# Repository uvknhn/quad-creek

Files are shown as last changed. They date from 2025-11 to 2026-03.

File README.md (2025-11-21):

# Quad Creek
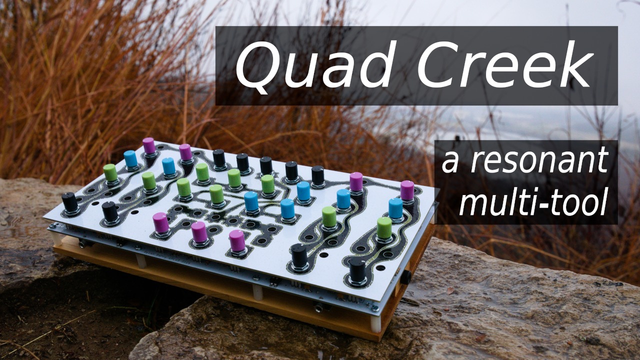
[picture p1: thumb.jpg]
Watch the video (https://www.youtube.com/watch?v=D_fRNRYVuKw)


[Webpage](https://loess-labs.net/inst/creek/)

[Etsy Shop](https://loesslabs.etsy.com)

[ASSEMBLY GUIDE](https://github.com/uvknhn/quad-creek/blob/main/docs/README.md)

Here's the page for my instrument, Quad Creek. The gerbers, source files, code, and schematics are available under the GNU GPLv3. Additionally you'll find a BOM in the build guide, which should be useful if you're building one. If you have any questions, email me at uvknhn@tutanota.com.

You can find the manual and other documentation on my webpage.

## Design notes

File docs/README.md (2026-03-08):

# How to assemble your Quad Creek kit/PCB

PCB_Step_0

Welcome! Here I'll walk you through the basic steps of how to solder a Quad Creek. This is NOT a beginner project, you don't have to be a seasoned veteran, but if this is your first time soldering, stop. Here I'll go over my general way of soldering, you don't have to do it exactly how I do, but this way is most efficient and easy for me. Solder with care. If you just got the PCB and not the DIY kit, refer to the BOM at the bottom of this page.

## Resistors & Diodes
PCB_Step_1
Solder these from the top. Make sure the diode band is on the same side as the silkscreen image, and make sure you put the BAT46s on the diodes with the S curve, and the 1N914s on the diodes with the straight band. If you're unsure of capacitor color codes, look it up. Lastly, make sure everything sits flush, you'll thank yourself later.

## Capacitors
PCB_Step_2
Also solder these from the top. Make sure the numbers match.

106\10uF Capacitor

Note the 10uF (106) capacitor that is soldered on the underside.

## IC Sockets, Transistors, & More
PCB_Step_3
To solder the IC sockets, insert, and then fold two opposite corner pins to secure the socket in place, and solder from the bottom. Ensure the notches are aligned, so no ICs are unintentionally placed upside-down. I solder the transistors from the bottom. You can do them from the top, but it's harder that way. Do not solder the voltage regulator backwards; very bad, high-temperature things happen when you do. Don't forget to do the jumpers either, you can use scrap leads to wire them as pictured.

## Power, Aux Jacks, & Other Bottom Components
PCB_Step_4
To solder the stereo aux jacks, I solder one pin to begin, then gently push the body of the jack to be flush, while the initial solder joint is being heated. Repeat for a second pin to anchor it, then solder the rest normally. This process is also used for the 2.1mm power jack. For the nano board, I socket the male pins into the female sockets, insert them into the PCB, place the nano board on top, solder the male pins to it, and then solder the female sockets to the board. This ensures the board can easily be inserted and removed from the board. Also if you bought a DIY kit the nano will come pre programmed, so you don't need to do anything there, though feel free to reprogram it if you'd like.

## Potentiometers
PCB_Step_5
**A note before soldering the potentiometers:** Use pliers or snippers to remove the small notch on top of the potentiometer, directly in front of the shaft. Soldering the poteniometers is a similar process to the aux. What I do is insert the potentiometers, solder just one pin on each pot, then when they've all had one joint soldered, I flip the board over and solder all 96 potentiometer pins from the bottom side. Do not solder the anchoring legs on the side until you're sure they're aligned enough to fit on the panel. You also don't need to solder them at all if you plan on screwing every potentiometer nut into the front panel.

## Final Steps

PCB_Step_6
PCB_Step_7

Once all your soldering is complete, test your quad creek. Turn the 5 mixer channels all the way counterclockwise, turn the 4 knobs at the tops of the creeks up the same, set the ones directly below those to about halfway, and see if there is sound coming out of the three outputs. If that works, I'd screw in all the banana jacks, the nylon standoffs, and do further testing with some banana plugs. Then once you have tested/feel confident it works, install the panel and enjoy!
**A note on installing the banana jacks:** Be wary not to overtighten. When tightening, hold the jack in place by applying downward pressure to the top of the jack, rather than holding from the sides. This prevents the plastic part at the top from being cross threaded and/or stripped out.

Also, if you got a PCB with no panel, or you simply want a custom panel, I've added a PDF with all of the holes from the original panel, which you can use as a reference for drilling and such.

There is also a PDF for the back panel, for drilling holes aligning with the standoffs.

## BILL OF MATERIALS

### RESISTORS

| Value | Qt. |
| :-- | --: |
| 1M | 6 |
| 100k | 56 |
| 10k | 35 |
| 1k | 18 |
| 2.2M | 1 |
| 220k | 17 |
| 22k | 12 |
| 2.2k | 2 |
| 47k | 6 |
| 4.7k | 1 |

### CAPACITORS

| Value | Code | Type | Qt. |
| :-- | :--: | :--: | --: |
| 220uF | 227 | Electr. | 1 |
| 10uF | 106 | MLCC | 7 |
| 4.7uF | 475 | MLCC | 2 |
| 1uF | 105 | MLCC | 16 |
| 100nF | 104 | MLCC | 32 |
| 10nF | 103 | MLCC | 10 |
| 1nF | 102 | MLCC | 12 |
| 100pF | 101 | MLCC | 1 |

### ICs

| Chip | Qt. |
| :-- | --: |
| TL082 | 6 |
| LM358 | 7 |
| CD4013 | 2 |
| L7809CV | 1 |
| ATMEGA328P Nano Board | 1 |

### TRANSISTORS

| Transistor | Qt. |
| :-- | --: |
| 2N3904 | 10 |
| BC548 | 1 |

### DIODES

| Diode | Qt. |
| :-- | --: |
| 1N914 | 25 |
| BAT46 | 16 |
| 1N4001 | 1 |

### I/O

| Part | Code | Qt. |
| :-- | :--: | --: |
| 4MM Banana | [Generic/Unknown](https://www.aliexpress.us/item/3256807503214936.html) | 32 |
| Potentiometer | RD901F-40-15K-B100K | 32 |
| Stereo Jack | PJ-324 | 5 |
| 2.1mm Jack | A-4118 | 1 |
| DIP Switch | DI-R02 | 2 |

### SOCKETS

| Type | Qt. |
| :-- | --: |
| 15 Pin Socket | 2 |
| 14 Pin DIP Socket | 2 |
| 8 Pin DIP Socket | 13 |

### Knobs
| Part | Code | Qt. |
| :-- | :--: | --: |
| Black Knob | [A-6351](https://www.taydaelectronics.com/black-control-knob-9-8x11mm-shaft-hole-6x18t.html)/["Stubby"](https://www.thonk.co.uk/shop/stubby-knobs-t18/) | 9 |
| Blue Knob | [A-6352](https://www.taydaelectronics.com/blue-control-knob-9-8x11mm-shaft-hole-6x18t.html) | 7 |
| Green Knob | [A-6353](https://www.taydaelectronics.com/green-control-knob-9-8-x-11mm-shaft-hole-6x18t.html) | 9 |
| Purple Knob | [A-5666](https://www.taydaelectronics.com/purple-control-knob-9-8-x-11mm-shaft-hole-6x18t-5666.html) | 7 |

### Mechanical
| Type | Qt. |
| :-- | --: |
| M3×15mm Nylon Standoff | 19 |
| M3×4mm Screw | 19 |
| M3×10mm Screw | 19 |

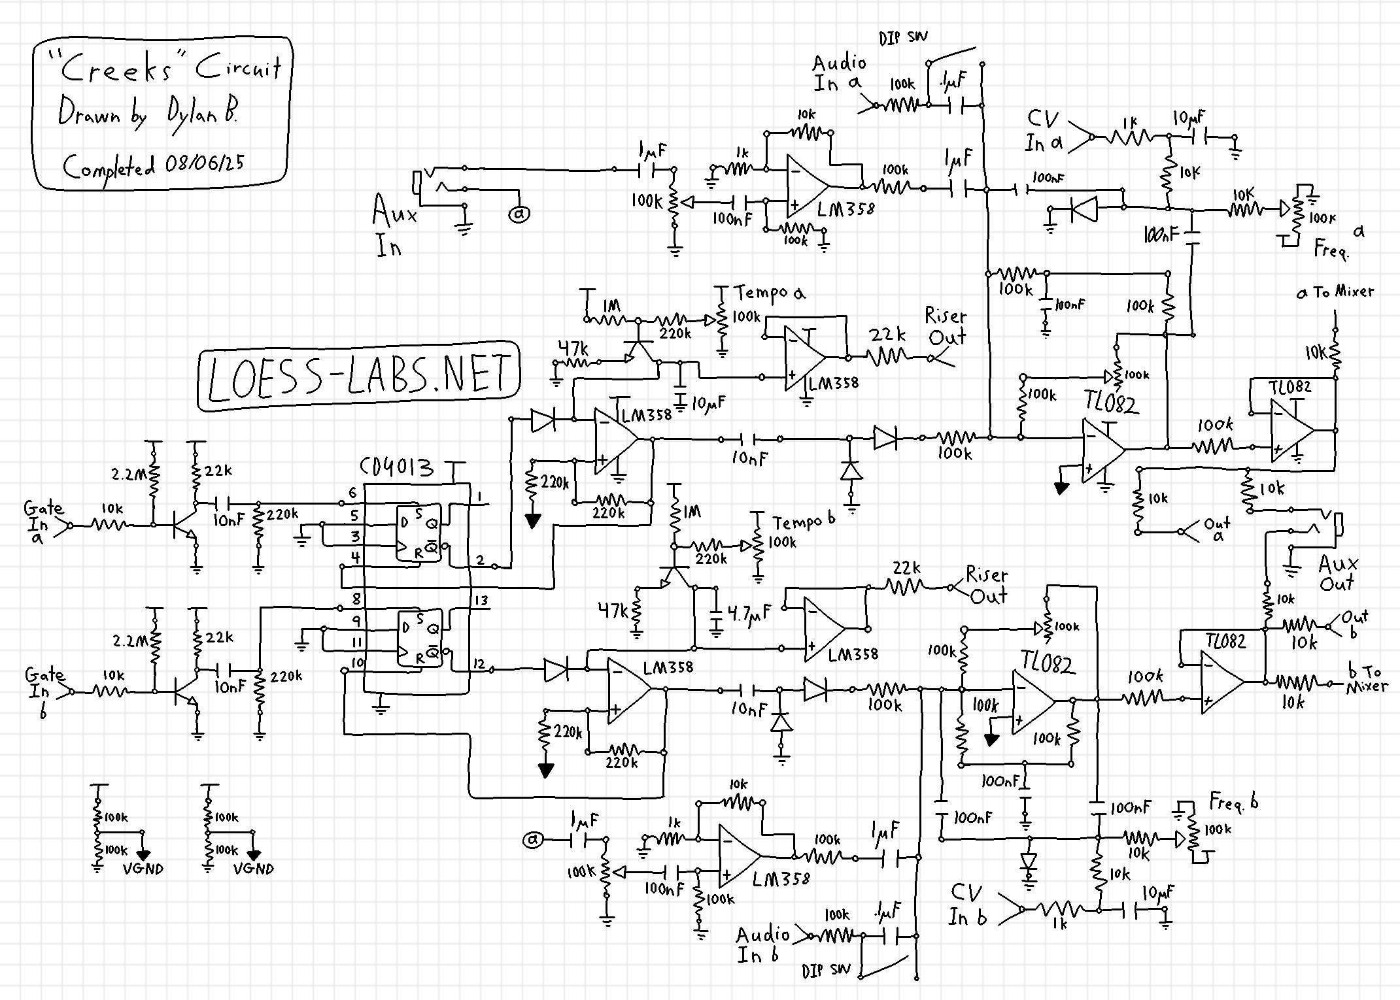
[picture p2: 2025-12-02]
docs/schem/The_Creeks_Schematic.gif

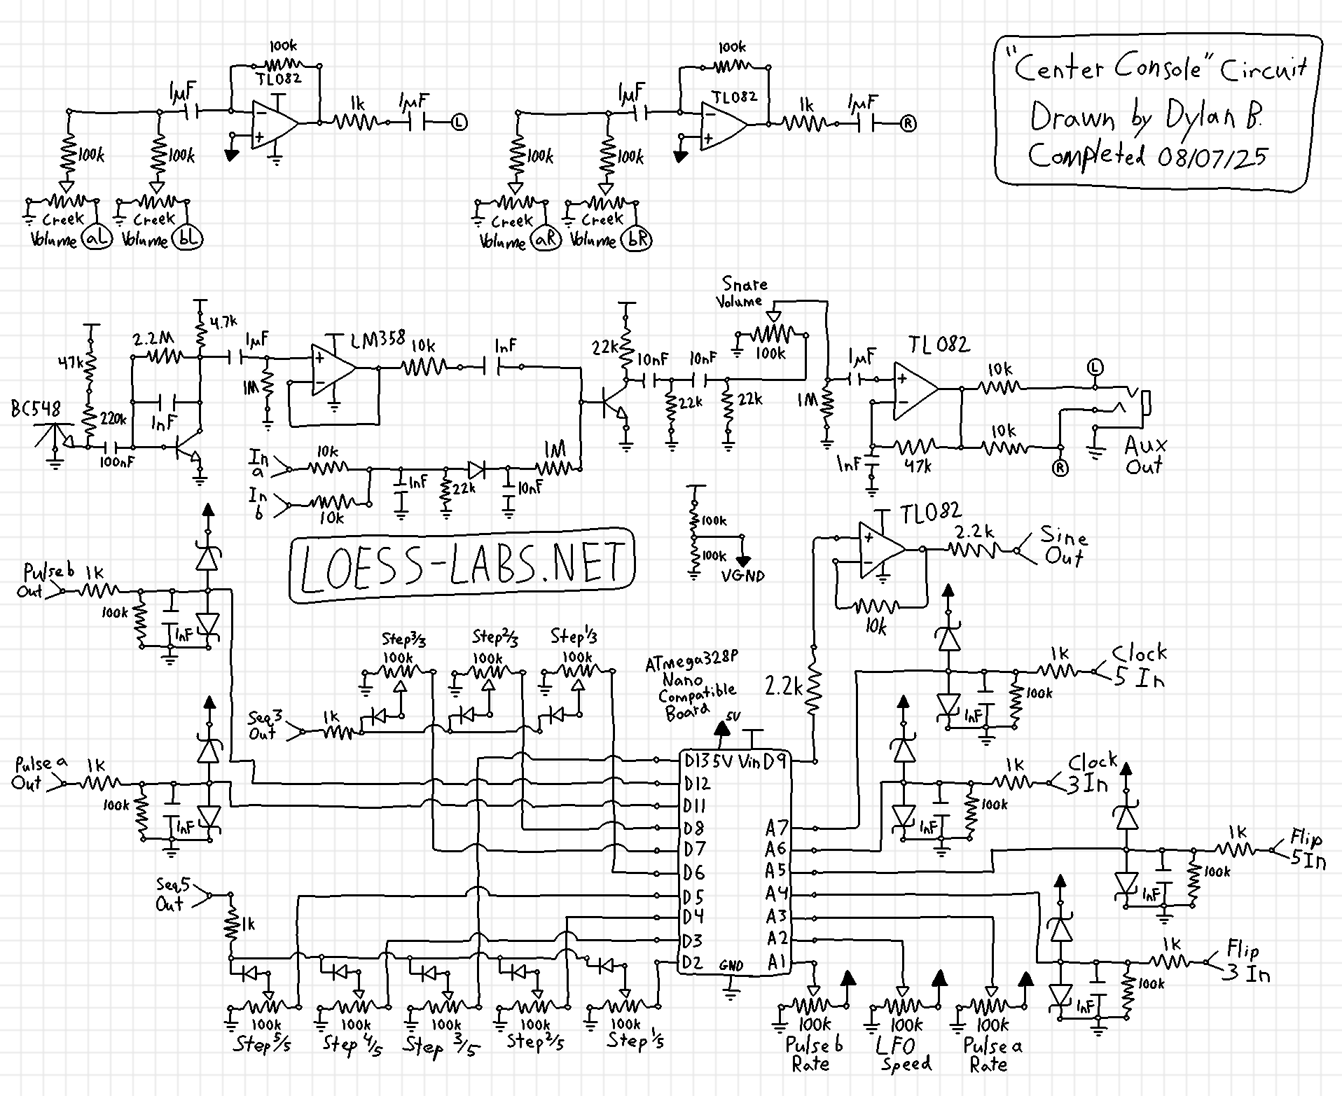
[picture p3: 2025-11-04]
docs/schem/Center_Console_Schematic.gif

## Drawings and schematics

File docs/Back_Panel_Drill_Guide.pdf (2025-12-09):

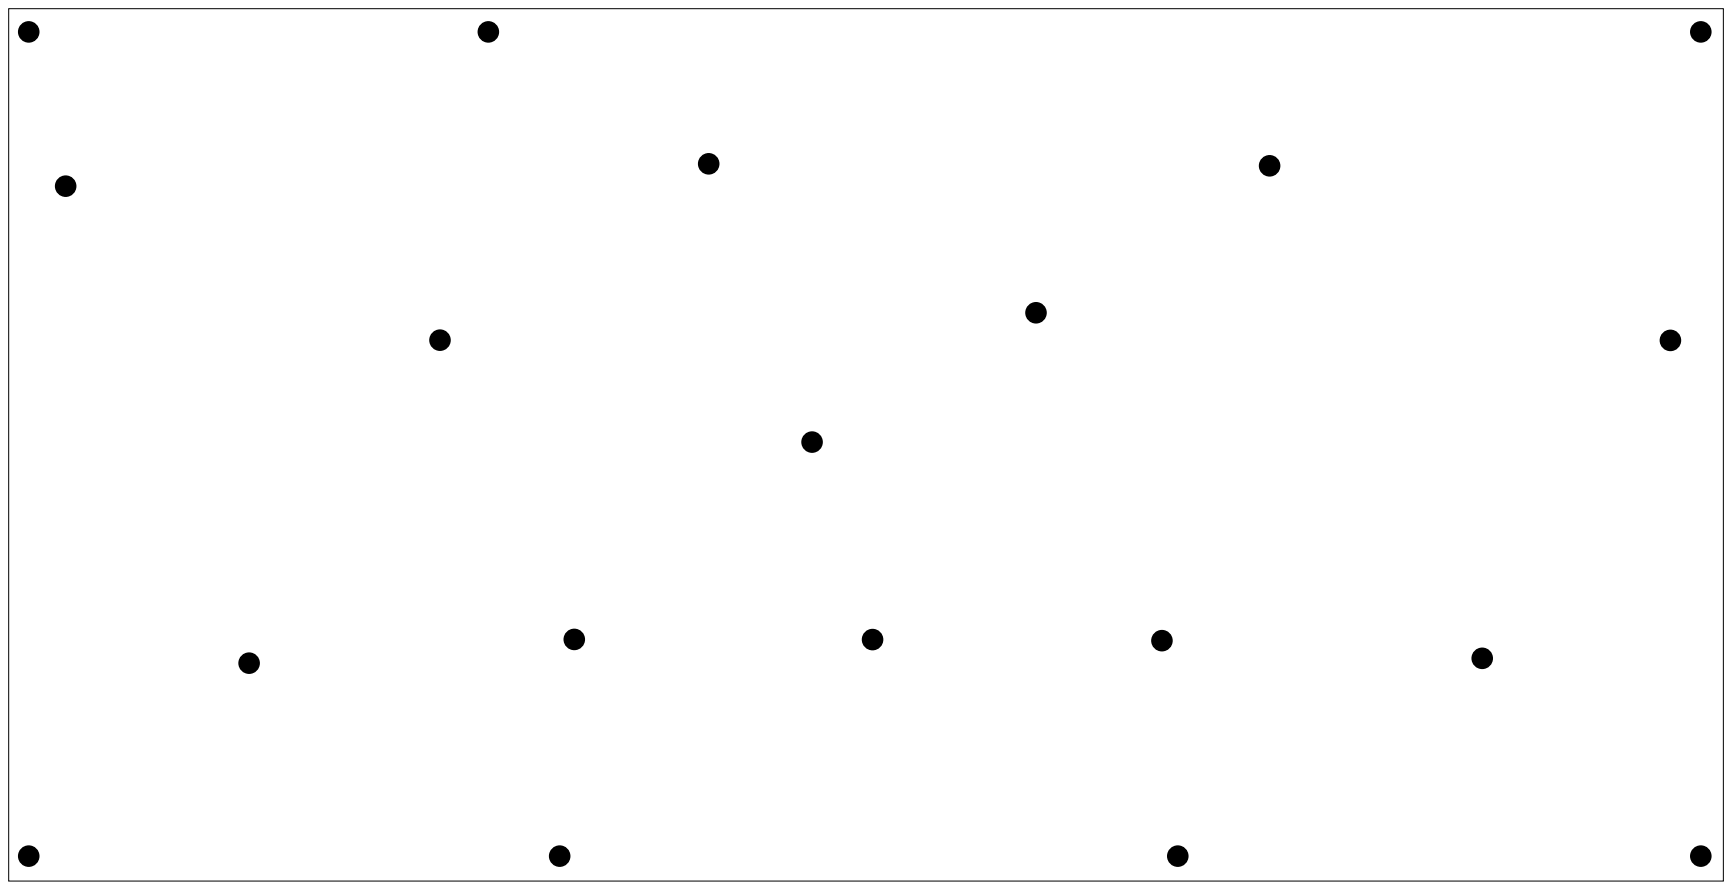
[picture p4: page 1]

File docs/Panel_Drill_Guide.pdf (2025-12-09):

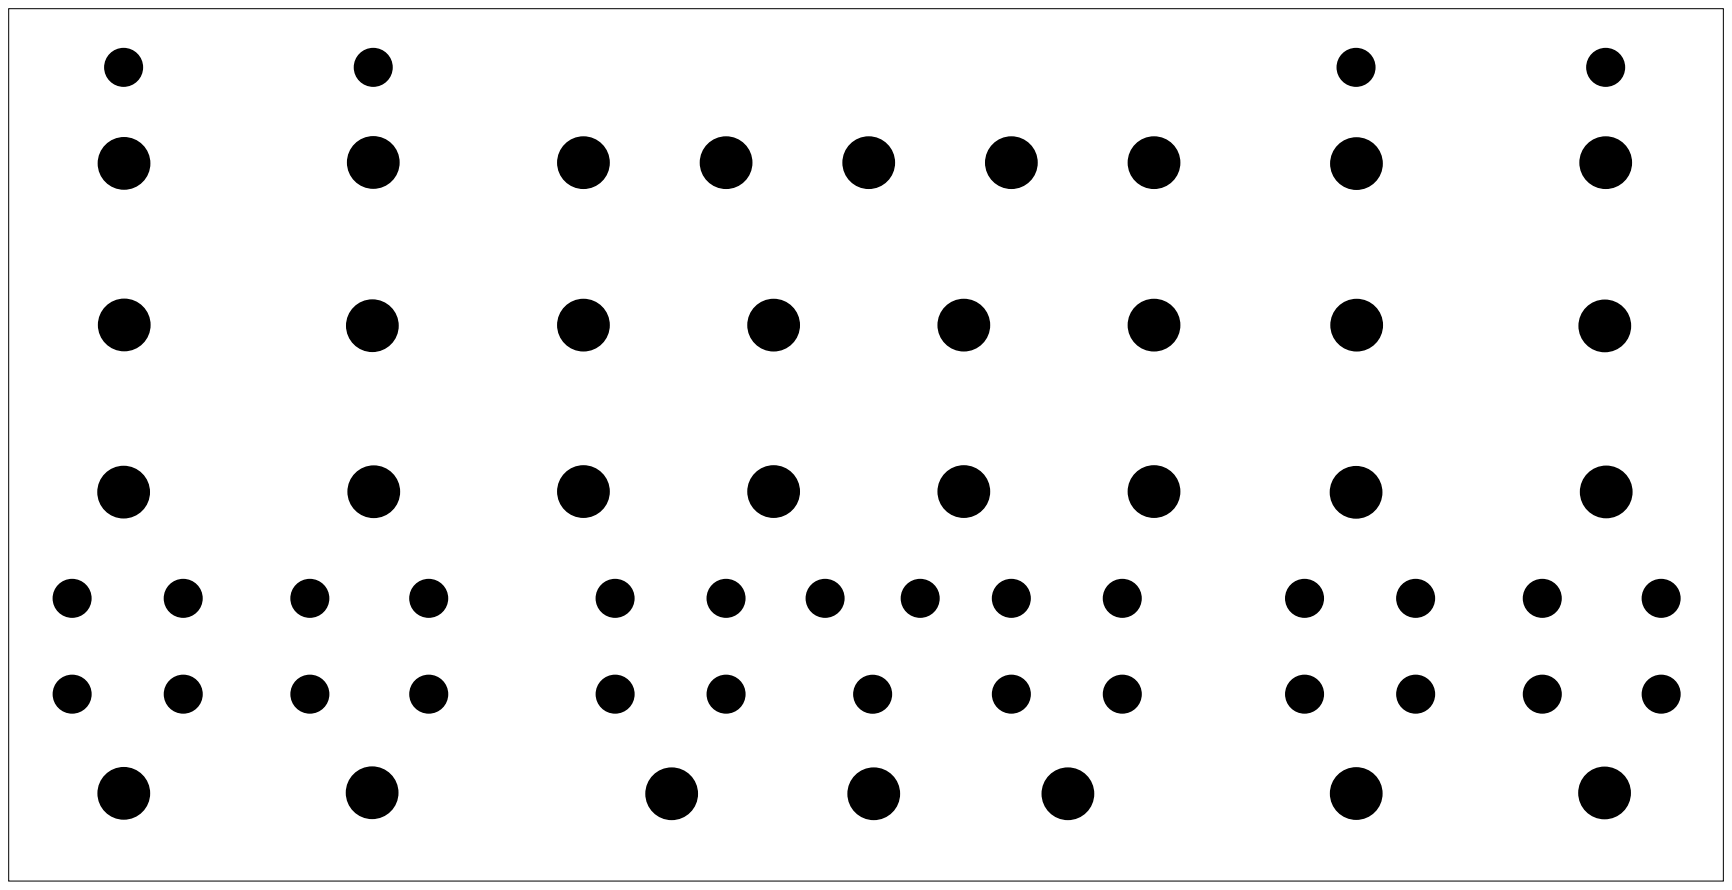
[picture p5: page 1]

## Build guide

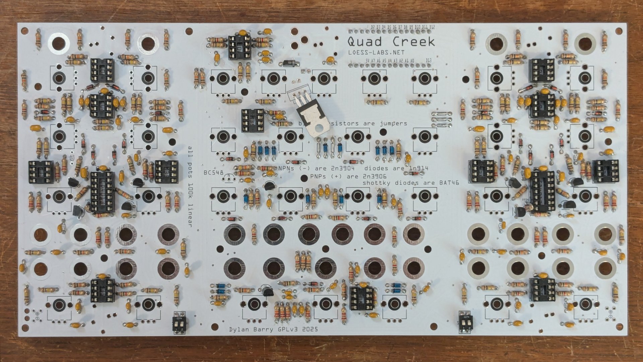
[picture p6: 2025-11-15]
docs/img/PCB_Step_3.jpg

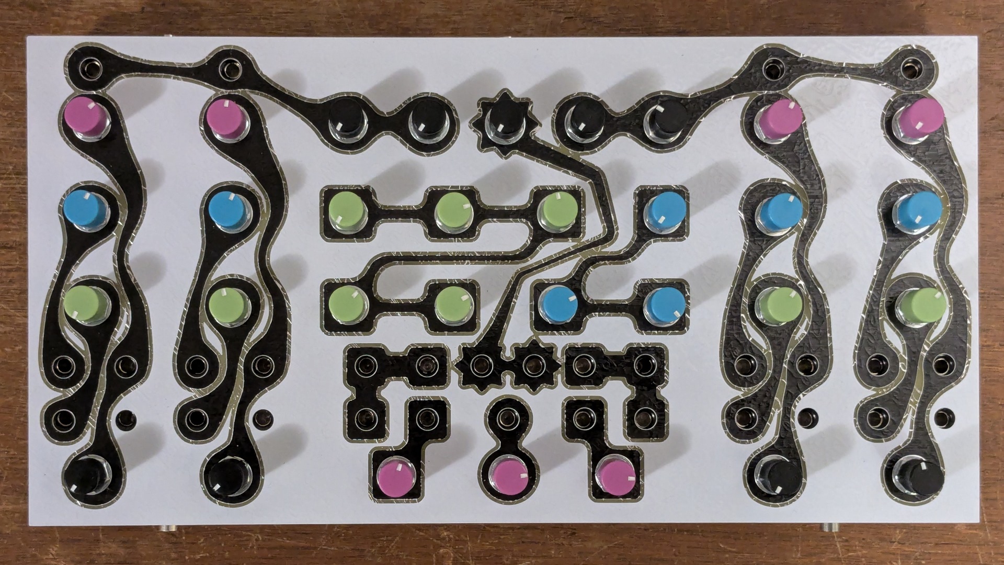
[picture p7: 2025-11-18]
docs/img/PCB_Step_7.jpg

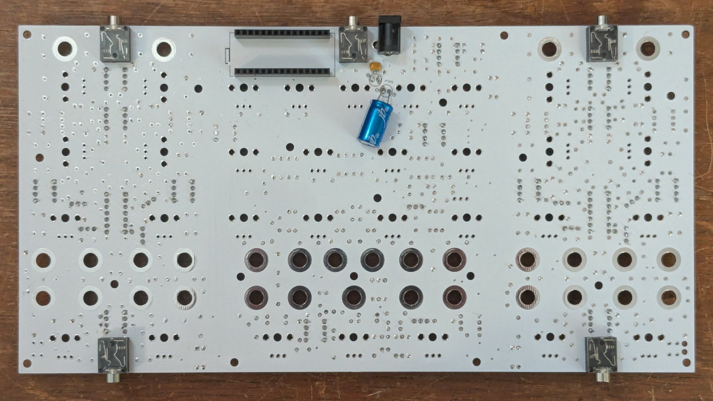
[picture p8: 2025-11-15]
docs/img/PCB_Step_4.jpg

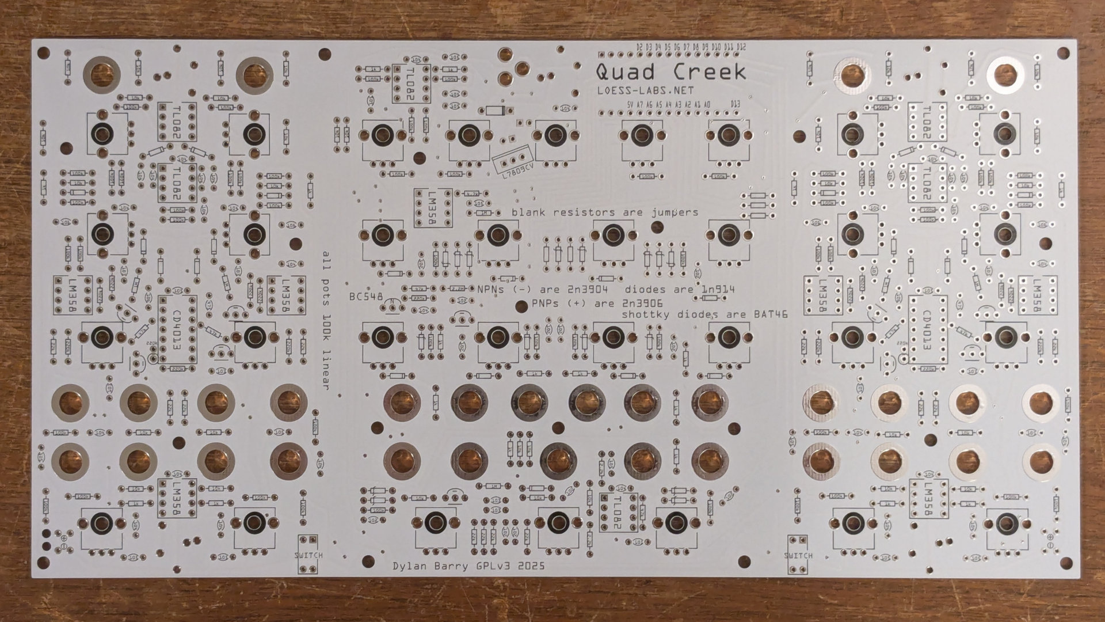
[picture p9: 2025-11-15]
docs/img/PCB_Step_0.jpg

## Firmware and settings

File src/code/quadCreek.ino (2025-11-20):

// LOESS-LABS.NET
// Dylan Barry, 2025, GNU GPLv3

#include <MozziGuts.h>
#include <Oscil.h>
#include <tables/sin2048_int8.h>
#include <math.h> 

#define CONTROL_RATE 128

// Analog Input Pins
const byte AUDIO_FREQ_PIN = 2;
const byte LFO_RATE_A_PIN = 3;
const byte LFO_DIVISOR_PIN = 1;     // Division ratio for sub-LFO
const byte FIVE_STEP_GATE_PIN = 7;  // Clock in for 5 stepper
const byte FLIP_GATE_PIN = 5;       // Clock in for 5 step flip
const byte THREE_STEP_GATE_PIN = 6; // Clock in for 3 stepper
const byte THREE_STEP_FLIP_PIN = 4; // Clock in for 3 step flip

// Digital Output Pins
const byte LFO_PIN_A = 11;
const byte LFO_PIN_B = 12;

// Sequencer Pin Arrays
const byte FIVE_STEP_PINS[] = {2, 4, 13, 3, 5};
const int FIVE_STEP_COUNT = sizeof(FIVE_STEP_PINS) / sizeof(FIVE_STEP_PINS[0]);
const byte THREE_STEP_PINS[] = {6, 8, 7};
const int THREE_STEP_COUNT = sizeof(THREE_STEP_PINS) / sizeof(THREE_STEP_PINS[0]);

// SENSITIVITY CONSTANTS

// Lowering the threshold makes it trigger on weaker signals.
const int GATE_THRESHOLD = 800; 

// Define the fixed HIGH time (pulse width) in milliseconds for LFO A and LFO B.
// This makes the pulse a stable trigger signal, independent of the overall frequency.
const unsigned long LFO_A_FIXED_PULSE_MS = 10UL; // 10ms pulse width

// Define the min/max range for the main audio carrier (Sine LFO) frequency
const float CARRIER_FREQ_MIN = 0.01f;
const float CARRIER_FREQ_MAX = 18.0f;

// Define the min/max range for the LFO A Period (in milliseconds)
const float LFO_PERIOD_MIN_MS = 20.0f; // Max speed (50 Hz)
const float LFO_PERIOD_MAX_MS = 6000.0f; // Min speed (0.166 Hz)


// The array of possible divisors for LFO B
const int DIVISORS[] = {2, 3, 4, 5, 6};
const int DIVISOR_COUNT = sizeof(DIVISORS) / sizeof(DIVISORS[0]);

// STATE VARIABLES
Oscil<SIN2048_NUM_CELLS, MOZZI_AUDIO_RATE> aCarrier(SIN2048_DATA);

// Timers
unsigned long lfoAPreviousMillis = 0; // LFO A Pulse Timer
unsigned long lfoBPreviousMillis = 0; // LFO B Pulse Timer
unsigned long cPreviousMillis = 0; // 5 Stepper Gate Clock
unsigned long dPreviousMillis = 0; // 5 Stepper Flip Gate Clock
unsigned long ePreviousMillis = 0; // 3 Stepper Gate Clock
unsigned long fPreviousMillis = 0; // 3 Stepper Flip Gate Clock

// LFO State
int lfoACount = 0;     // Counts full cycles (toggles) of LFO A
int lfoBDivisor = 2;   // Selected division (2, 3, 4, 5, or 6)
bool lfoAIsHigh = false; // Internal state tracking for LFO A
bool lfoBIsHigh = false; // Internal state tracking for LFO B

// Sequencer State
int aPreviousGate = 0; // For 5-Step clock rising edge detection
int bPreviousGate = 0; // For 5-Step Flip rising edge detection
int cPreviousGate = 0; // For 3-Step clock rising edge detection
int dPreviousGate = 0; // For 3-Step Flip rising edge detection
int fivStep = 2;       // Current step for 5-step sequencer
int triStep = 0;       // Current step for 3-step sequencer
int flip = 0;          // Direction control for 5-step sequencer (0=up, 1=down)
int triFlip = 0;       // Direction control for 3-step sequencer (0=up, 1=down)

// Exponential mapping for pot response
float mapExponentialFloat(int analogValue, float minOutput, float maxOutput, bool invert) {
    float normalizedValue = (float)analogValue / 1023.0f;

    if (invert) {
        normalizedValue = 1.0f - normalizedValue;
    }

    float logMin = log(minOutput);
    float logMax = log(maxOutput);

    float logResult = logMin + normalizedValue * (logMax - logMin);

    float result = exp(logResult);

    return max(minOutput, min(result, maxOutput));
}


void setup() {
  // Start Mozzi
  startMozzi(CONTROL_RATE);
  
  // Set all sequencer pins as outputs
  for (int i = 0; i < FIVE_STEP_COUNT; i++) {
    pinMode(FIVE_STEP_PINS[i], OUTPUT);
  }
  for (int i = 0; i < THREE_STEP_COUNT; i++) {
    pinMode(THREE_STEP_PINS[i], OUTPUT);
  }
  
  // Set LFO output pins
  pinMode(LFO_PIN_A, OUTPUT);
  pinMode(LFO_PIN_B, OUTPUT);
}

// SEQUENCER/CONTROL LOGIC FUNCTIONS

// Output logic for a sequencer using an array.
// Only the pin corresponding to the current step is set HIGH.

void updateSequencerOutputs(const byte pins[], int count, int currentStep) {
  for (int i = 0; i < count; i++) {
    // Check if the current pin index matches the current step
    if (i == currentStep) {
      digitalWrite(pins[i], HIGH);
    } else {
      digitalWrite(pins[i], LOW);
    }
  }
}

void updateControl() {
  unsigned long currentMillis = millis();

  // LFO Rate and Division Configuration
  
  // Exponential Mapping for LFO A Period: 
  int lfoAPeriodBase = (int)mapExponentialFloat(
      mozziAnalogRead(LFO_RATE_A_PIN), 
      LFO_PERIOD_MIN_MS, 
      LFO_PERIOD_MAX_MS, 
      true
  );
  
  // Calculate ON time (pulse width) and OFF time (space).
  unsigned long lfoAOnTime = LFO_A_FIXED_PULSE_MS;
  
  // OFF time is the total period minus the fixed ON time.
  unsigned long lfoAOffTime;
  if (lfoAPeriodBase <= lfoAOnTime) {
      lfoAOffTime = LFO_A_FIXED_PULSE_MS; 
  } else {
      lfoAOffTime = (unsigned long)lfoAPeriodBase - lfoAOnTime;
  }
  lfoAOffTime = max(lfoAOffTime, 1UL); 
  
  // LFO B Divisor: 
  int rawDivisorRead = mozziAnalogRead(LFO_DIVISOR_PIN);
  int divisorIndex = map(rawDivisorRead, 1023, 0, 0, DIVISOR_COUNT - 1); 
  lfoBDivisor = DIVISORS[divisorIndex];

  // Determine the time limit based on the current internal LFO state
  unsigned long timeLimit = lfoAIsHigh ? lfoAOnTime : lfoAOffTime;

  // LFO A Logic (Master Clock)
  if (currentMillis - lfoAPreviousMillis > timeLimit){
    lfoAPreviousMillis = currentMillis;
    lfoAIsHigh = !lfoAIsHigh;
    digitalWrite(LFO_PIN_A, lfoAIsHigh);
    if (lfoAIsHigh) { 
      lfoACount++;
    }
  }

  // LFO B Logic
  
  if (lfoACount >= lfoBDivisor) {
      lfoACount = 0;
      
      if (lfoBIsHigh == false) {
          lfoBIsHigh = true;
          lfoBPreviousMillis = currentMillis;
      }
  }

  if (lfoBIsHigh == true && (currentMillis - lfoBPreviousMillis >= LFO_A_FIXED_PULSE_MS)) {
      lfoBIsHigh = false;
  }

  digitalWrite(LFO_PIN_B, lfoBIsHigh);
  
  // Gate/Control Input Readings
  int aCurrentGate = mozziAnalogRead(FIVE_STEP_GATE_PIN); 
  int bCurrentGate = mozziAnalogRead(FLIP_GATE_PIN);                  
  int cCurrentRawGate = mozziAnalogRead(THREE_STEP_GATE_PIN);
  int dCurrentGate = mozziAnalogRead(THREE_STEP_FLIP_PIN);

  // 5-Step Sequencer (Clocked by A7)
  // Rising edge detection check: Trigger when signal crosses threshold AND is rising
  if (currentMillis - cPreviousMillis > 10 && aCurrentGate > GATE_THRESHOLD && aPreviousGate < aCurrentGate){
    cPreviousMillis = currentMillis;
    
    if (flip == 1){
      fivStep--;
    } else {
      fivStep++;
    }
    
    if (fivStep >= FIVE_STEP_COUNT) {
      fivStep = 0;
    } else if (fivStep < 0) {
      fivStep = FIVE_STEP_COUNT - 1; 
    }
  }
  aPreviousGate = aCurrentGate;

  // 5-Step Flip Control
  // Rising edge detection check: Trigger when signal crosses threshold AND is rising
  if (currentMillis - dPreviousMillis > 10 && bCurrentGate > GATE_THRESHOLD && bPreviousGate < bCurrentGate){
    dPreviousMillis = currentMillis;
    flip = 1 - flip;
  }
  bPreviousGate = bCurrentGate;
  
  // 3-Step Sequencer
  // Rising edge detection for 3-step clock for reliable triggering
  if (currentMillis - ePreviousMillis > 10 && cCurrentRawGate > GATE_THRESHOLD && cPreviousGate < cCurrentRawGate){
    ePreviousMillis = currentMillis;
    
    if (triFlip == 1){
      triStep--;
    } else {
      triStep++;
    }
    
    if (triStep >= THREE_STEP_COUNT){
      triStep = 0;
    } else if (triStep < 0) {
      triStep = THREE_STEP_COUNT - 1; 
    }
  }
  cPreviousGate = cCurrentRawGate; 

  // 3-Step Flip Control
  // Rising edge detection check: Trigger when signal crosses threshold AND is rising
  if (currentMillis - fPreviousMillis > 10 && dCurrentGate > GATE_THRESHOLD && dPreviousGate < dCurrentGate){
    fPreviousMillis = currentMillis;
    triFlip = 1 - triFlip;
  }
  dPreviousGate = dCurrentGate;
  
  // Frequency Control
  int sensorValue = mozziAnalogRead(AUDIO_FREQ_PIN);
  
  // Exponential mapping for sine LFO frequency
  float newFreq = mapExponentialFloat(
      sensorValue, 
      CARRIER_FREQ_MIN, 
      CARRIER_FREQ_MAX, 
      false
  );
  
  aCarrier.setFreq(newFreq);

  // SEQUENCER OUTPUTS
  updateSequencerOutputs(FIVE_STEP_PINS, FIVE_STEP_COUNT, fivStep);
  updateSequencerOutputs(THREE_STEP_PINS, THREE_STEP_COUNT, triStep);
}

AudioOutput_t updateAudio() {
  return MonoOutput::from8Bit(aCarrier.next());
}

void loop() {
  audioHook();
}
